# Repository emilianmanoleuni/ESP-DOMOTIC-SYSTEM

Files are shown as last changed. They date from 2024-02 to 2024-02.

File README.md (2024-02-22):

# ESP DOMOTIC SYSTEM
ESP Domotic System is a simple domotic system to control sensors and domotic items of a small house. It is associated to a web app that allows to check real-time graphs of power consumption and sensor readings. The web app also allows to turn on and off domotic items such as lights or fans. This project exploits the concept of embedded systems to simplify control of a small house. It also offers the possibility to give several voice commands through a voice model, for example to turn on or off lights.
### Schematic

 <p>
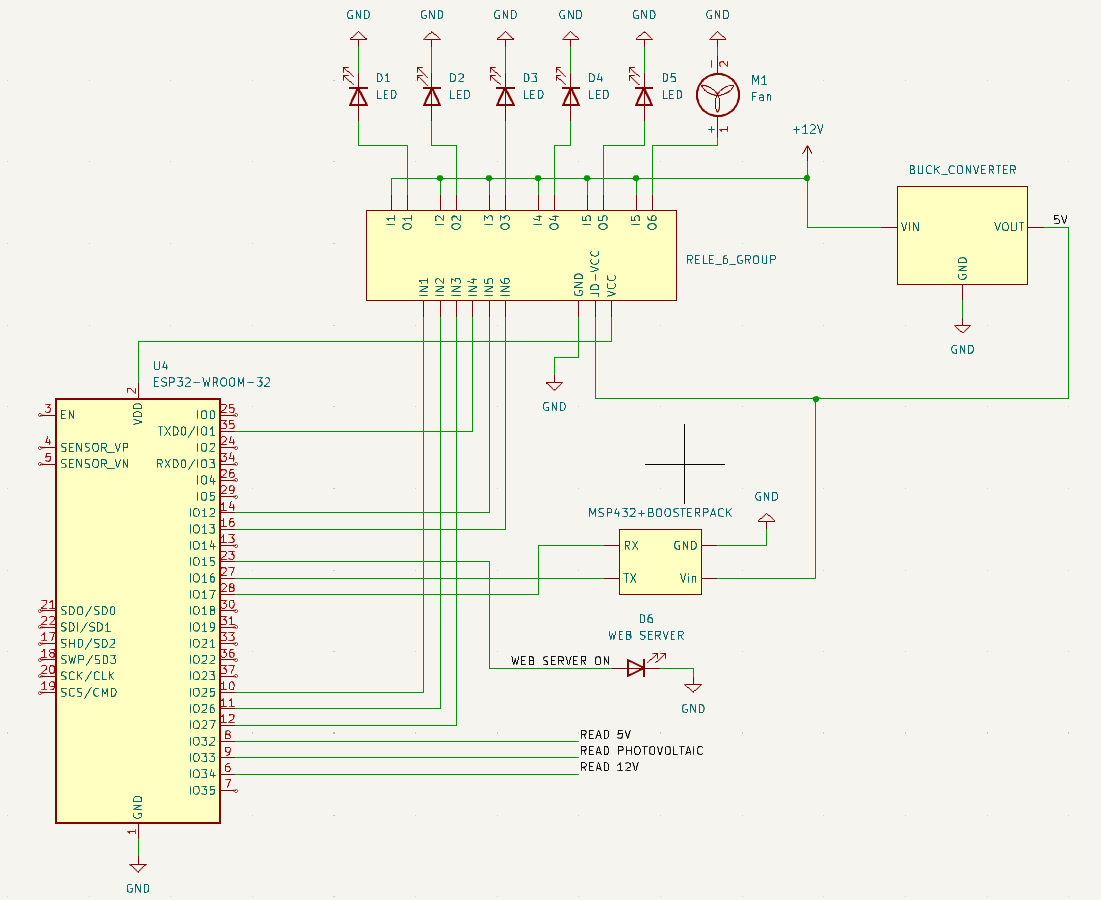
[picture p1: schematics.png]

</p>

 ## Requirements 

 ### Hardware requirements
 ESP Domotyc System requires:
 * Texas Instruments MSP432P401R with BoosterPack
 * 2 x ESP32
 * Relay module
 * Matrix Board
 * Buck converter and resistance
 * INMP441 microphone
 * 5 x LED stripes 12V
 * 12V power supply
 * Solar panel
 * 12V fan

### Software requirements
You will need [Code Composer Studio](https://www.ti.com/tool/CCSTUDIO) installed with [DriverLib](https://www.ti.com/tool/MSPDRIVERLIB) to compile and run the code on the MSP. You will also need [Arduino IDE 1.x](https://www.arduino.cc/en/software) to run the ESPs. 
>Using the 2.x version of the IDE may cause some bugs with the file system

## Project Layout

```

├── esp_main                
│   ├── esp_main_code        # main code to be run on the main esp
│   ├── esp_main_data        # data of the web server held on the esp
├── ESP_SpeechToText         # main code to be run on the voice module esp
├── ServerGoogleAPI          # connection to google server
├── msp432                   # project to be imported in CodeComposerStudio
├── house_model              # 3D model to print house model anb brackets for components
```

## Build and Run the project

After connecting the devices as indicated in the [schematic](#schematic), you have to upload programs on each board.
Starting from the MSP432:
1. Open CodeComposerStudio
2. Go to **File** > **Open Projects from File Systems**
3. In **Import Projects from File Systems** search and select the project.

To add the DriverLib:
1. Go to **Build** > **Arm Linker** > **File Search Path** and add the paths where you installed the library

Once you have done that you can right-click on the main project folder and click on **Build Project**, once ended you can click **Flash** on CCS to upload the code on the MSP432.

For the main ESP: 
1. Open Arduino IDE 1.x
2. Select the board "ESP32 dev module"
3. Go to **File** > **Open** and select the .ino file

For the second ESP: 
1. Open Arduino IDE 1.x
2. Select the board "ESP32 dev module"
3. Go to **File** > **Open** and select the .ino file

> Be sure that the GoogleServerAPI directory is in the same directory as the project and don't rename any file

When you have uploaded and verified both projects, you can upload them on each board by clicking the arrow in Arduino IDE.
To upload the data directory into the memory of the main ESP, you need to use a file system. In this case we use the integrated LittleFS.
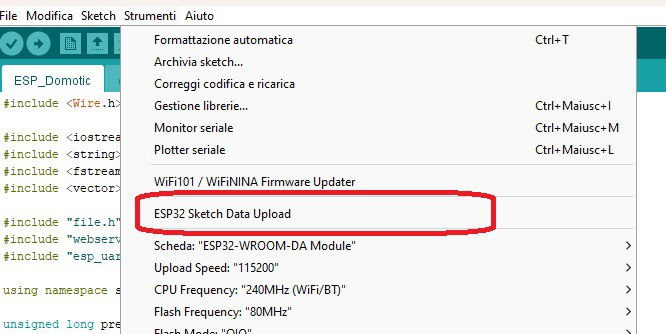
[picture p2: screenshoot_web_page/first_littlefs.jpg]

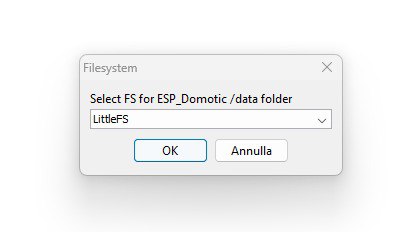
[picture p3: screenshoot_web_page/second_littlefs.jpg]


## User Guide 
 After the connections are ready and the boards are powered, wait that the blue led on the main ESP turn on. This means that the server is ready and you can proceed accessing the web app.
 To do so, open the Arduino console and read the main ESP IP address, copy it into your browser (pay attention to be connected at the same WiFi of the board) and this page will show up:
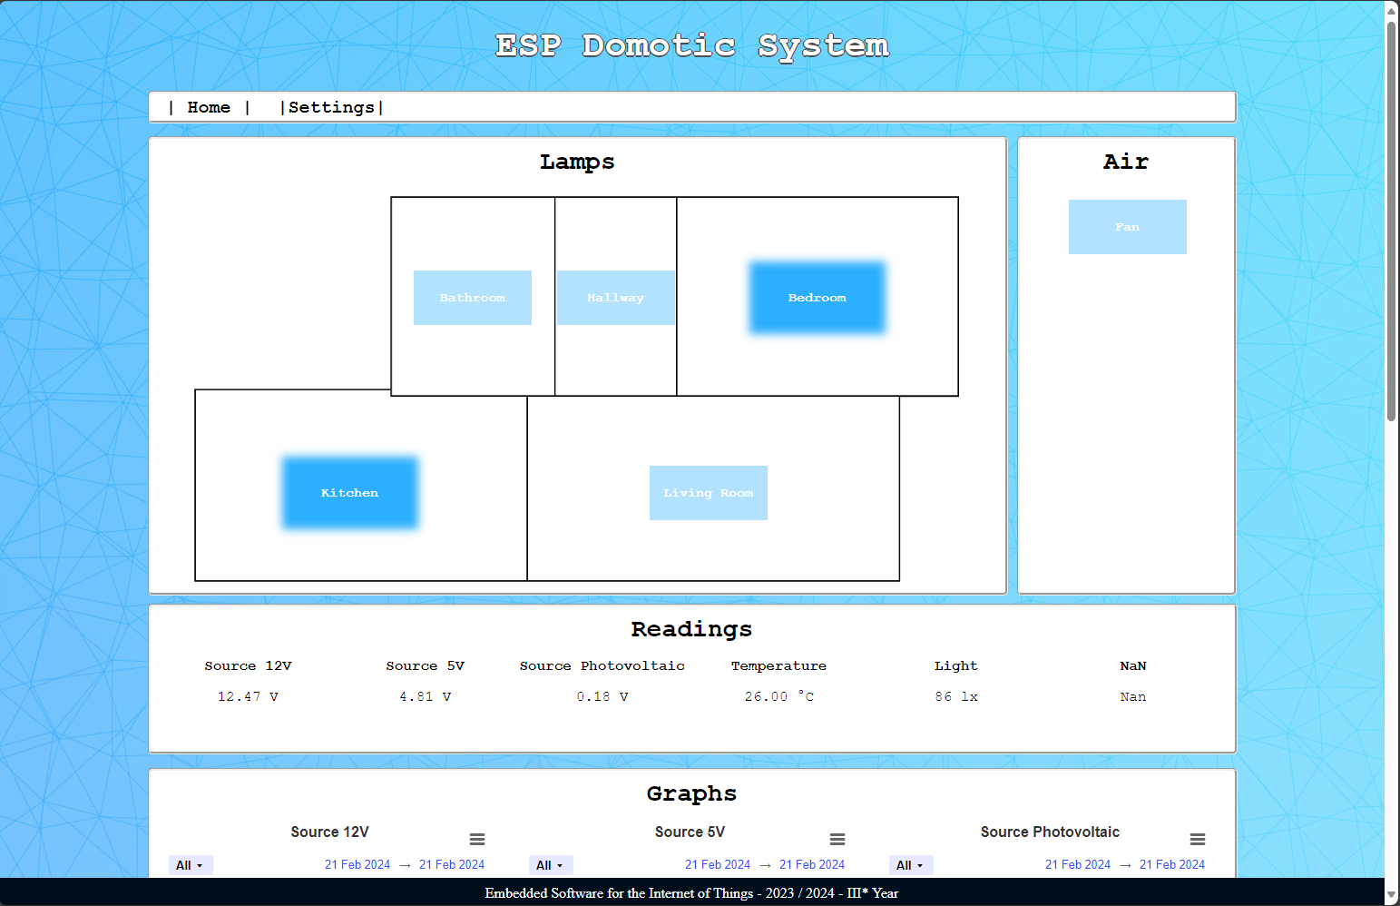
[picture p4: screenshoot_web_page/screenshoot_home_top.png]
 

 >The IP is assigned by the modem after you connect the ESP to it, modifying the ssid and password variables in ESP_Domotic.ino

 You can use those buttons to turn on/off lights and fan. When the blue is bright it means the power is on, otherwise it's off. Scrolling down you will see the graphs, that monitors all the sensors and power supplies of the sistem.

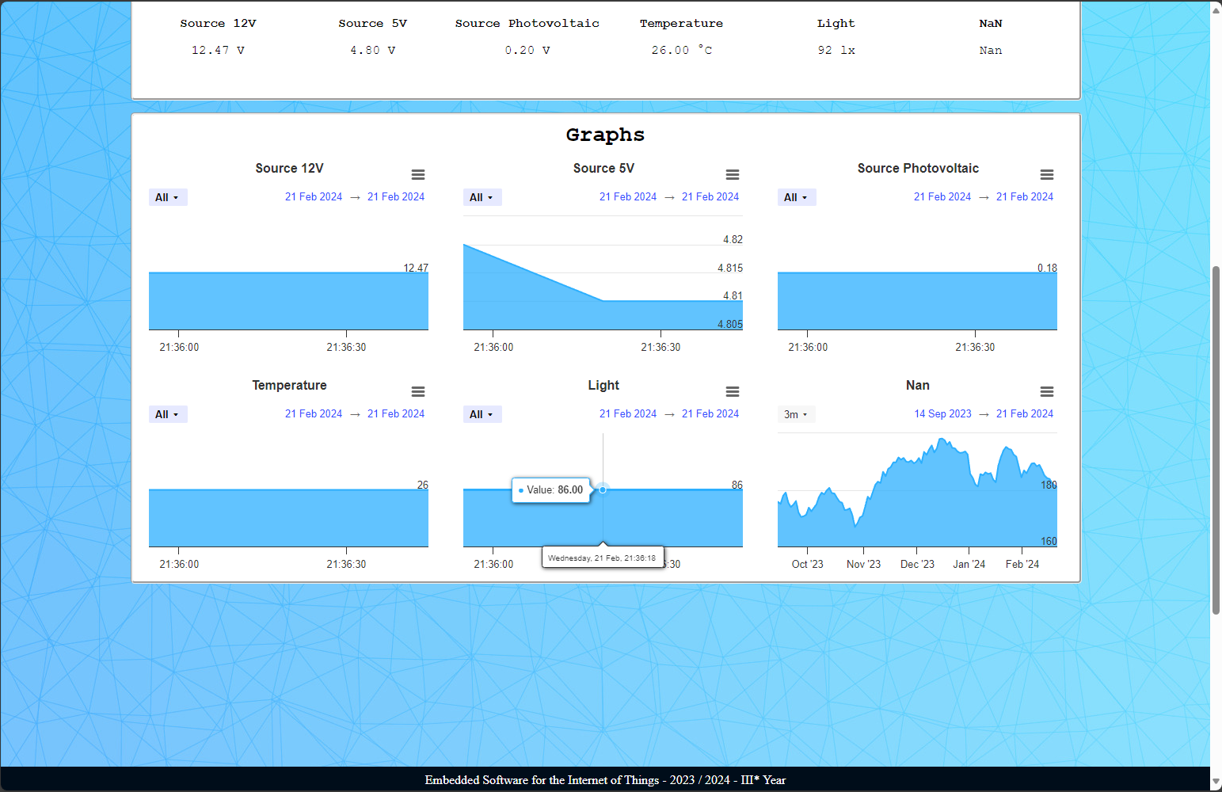
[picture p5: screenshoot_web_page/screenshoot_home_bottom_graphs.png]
 

 You can also use a various set of voice command, composed in this way:
 * If you want to turn or/off lights the command is "_ROOM_ + LIGHTS + ON/OFF"
 * If you want to turn or/off the fan the command is "FAN + ON/OFF"

> Available rooms: LIVING ROOM, KITCHEN, BATHROOM, BEDROOM, HALLWAY.

Just click the button and say the desired command. The command will execute in few seconds.

## Contributors

<table>
    <tr>
        <td>House model and cabling</td>
        <td>Emilian Manole</td>
    </tr>
    <tr>
        <td>Web app and Async server</td>
        <td>Emilian Manole</td>
    </tr>
    <tr>
        <td>MSP432</td>
        <td>Leonardo Rigotti</td>
    </tr>
    <tr>
        <td>UART communication</td>
        <td>Leonardo Rigotti</td>
    </tr>
    <tr>
        <td>First ESP</td>
        <td>Emilian Manole, Leonardo Rigotti</td>
    </tr>
    <tr>
        <td>Second ESP</td>
        <td>Elia Avanzolini, Riccardo Randon</td>
    </tr>
    <tr>
        <td>Voice Module</td>
        <td>Elia Avanzolini, Riccardo Randon</td>
    </tr>
</table>

[Video](https://youtu.be/A26lvR3nOL4) [Presentation](presentation/ESP_DomoticHouse_presentation.pdf)

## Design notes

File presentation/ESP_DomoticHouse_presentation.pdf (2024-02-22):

# DOMOTIC

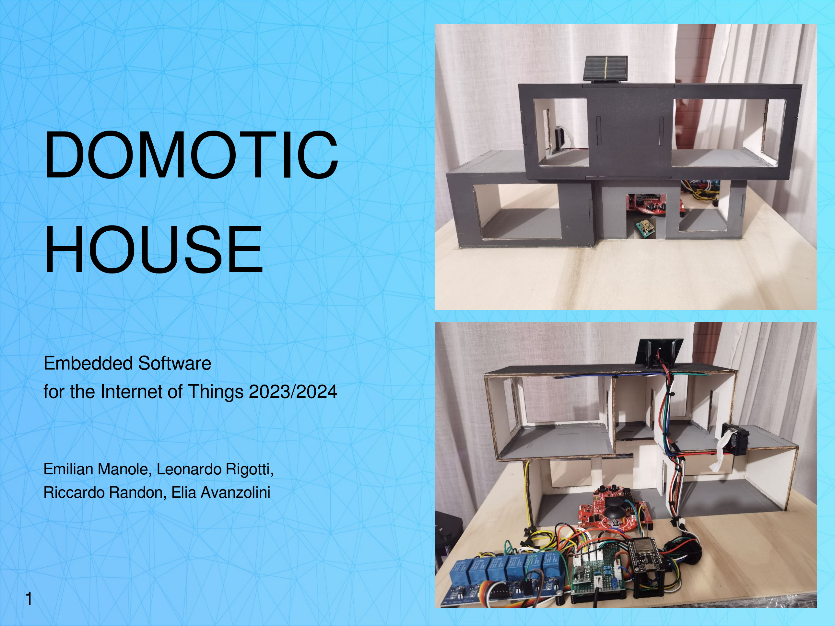
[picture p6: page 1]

# HOUSE

Embedded Software

for the Internet of Things 2023/2024

Emilian Manole, Leonardo Rigotti, Riccardo Randon, Elia Avanzolini

# BASIC MODUS OPERANDI

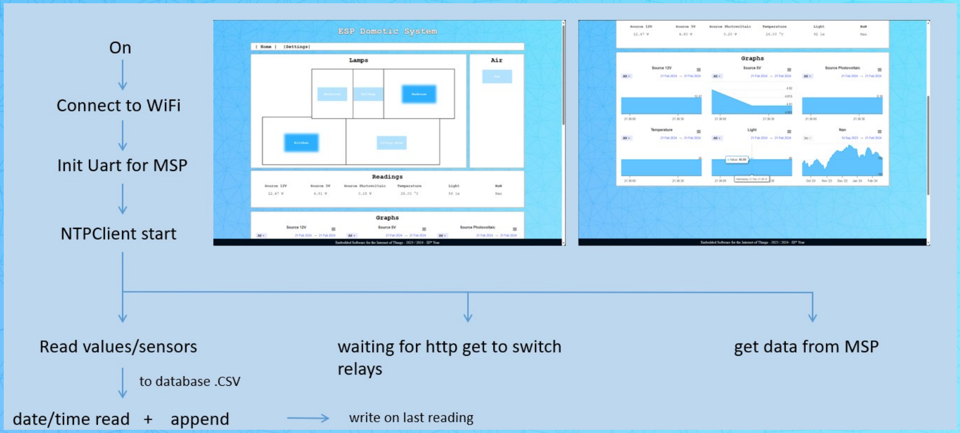
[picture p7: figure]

# MSP432 timer and interrupts

- Continous mode timer
- ACLK at 32kHz, divided by 14 so ~2.2kHz
- Overflows when hits 0xFFFF, around every 28s and sends an interrupt

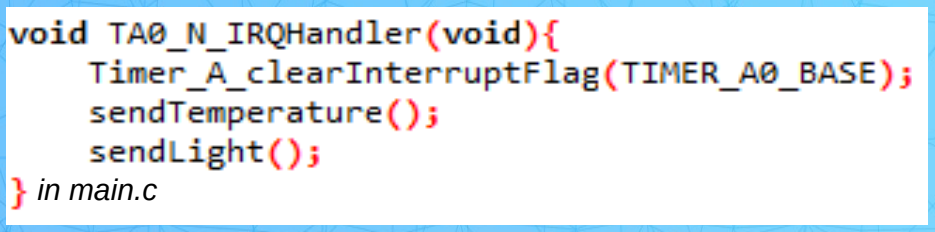
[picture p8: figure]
in main.c

- MCU is in LPM0 (ACLK and SMCLK active)
- ISR sends data via UART to other device
- return to LPM0:
- Interrupt_enableSleepOnIsrExit();
- interrupt on EUSCIA2 (pin 3.2, 3.3)
- executes when something is received via the UART receiver
- stores the data in a global variable and clear flags

# MSP432-ESP32 UART communication

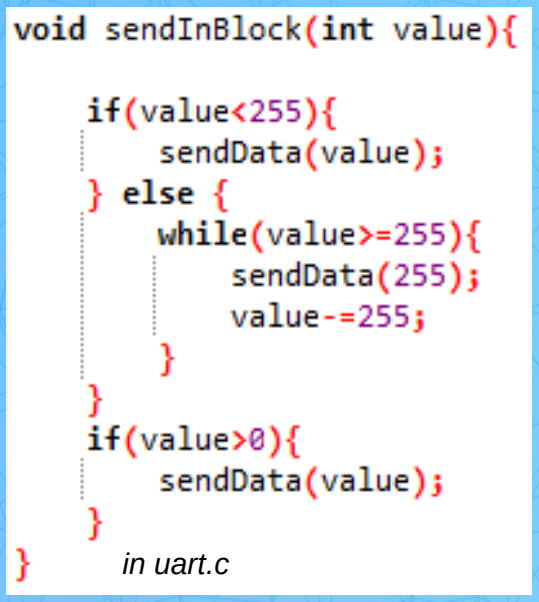
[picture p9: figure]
in uart.c

PROBLEM: only 1 byte via UART SOLUTION: send data that is >=

255 (max value with a byte)
in smaller blocks ...

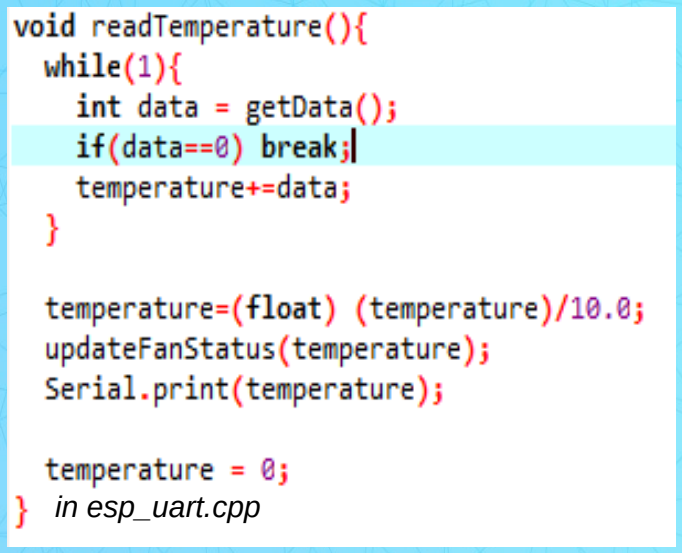
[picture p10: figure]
in esp_uart.cpp

… that get sum up on the ESP side

- EUSCI UART configuration
- 24MHz (SMCLK source), 115200 baudrate, no parity bit, one stop bit, 8 bit long message
- Using eUSCI 2, i.e. pin 3.2 and 3.3

# Voice Command

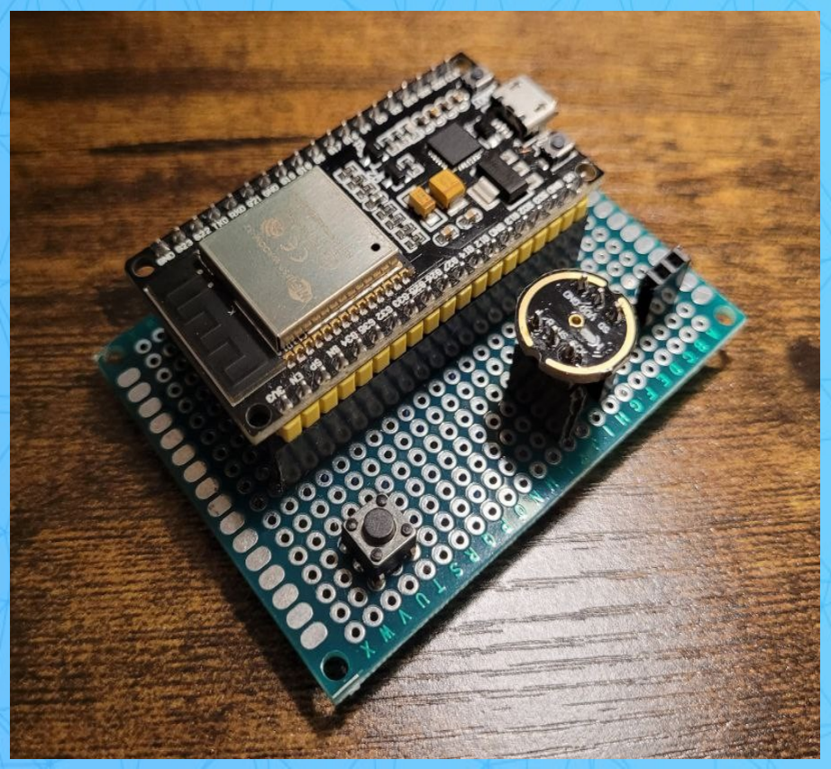
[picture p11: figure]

We utilized an ESP32 board to capture audio signals

from an INMP441 microphone using the I2S protocol.

Due to the high data rate, we employ DMA to store the incoming data in memory.

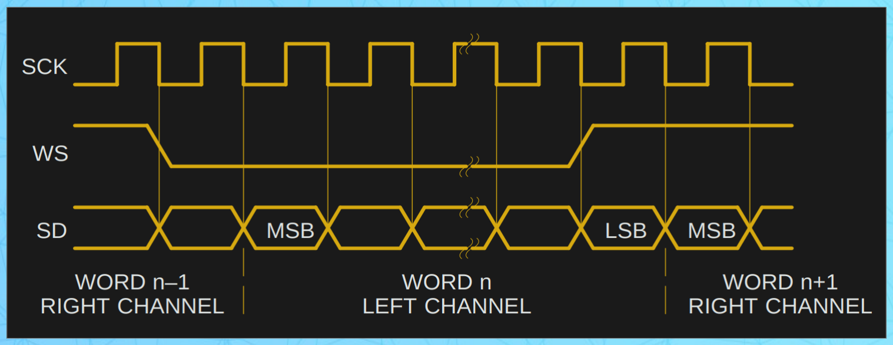
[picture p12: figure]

Afterwards, we utilize flash memory to store the file and produce the necessary WAV audio file format as per Google APIs.

# Speech to Text API

Once we obtain the WAV file, ESP32 sends it to the PC's Python server.
Here, with the assistance of the library provided by Google, we send a request to the Speech-to-Text APIs.

The response comes as a JSON file, which we extract the needed information from,

then send an integer containing home automation configurations back to ESP32.

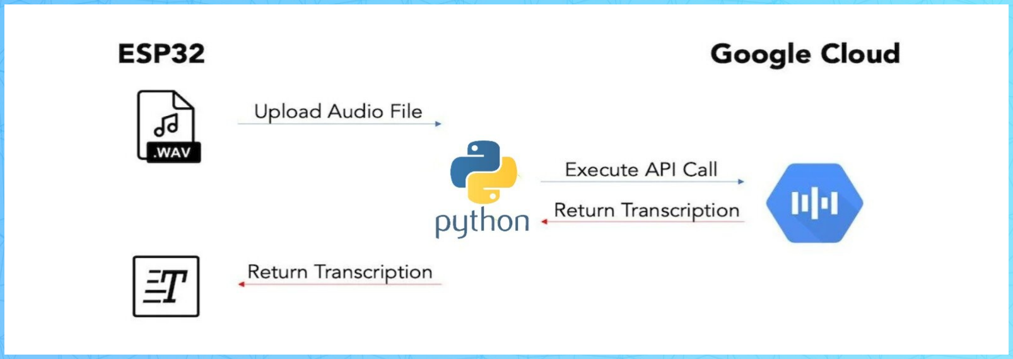
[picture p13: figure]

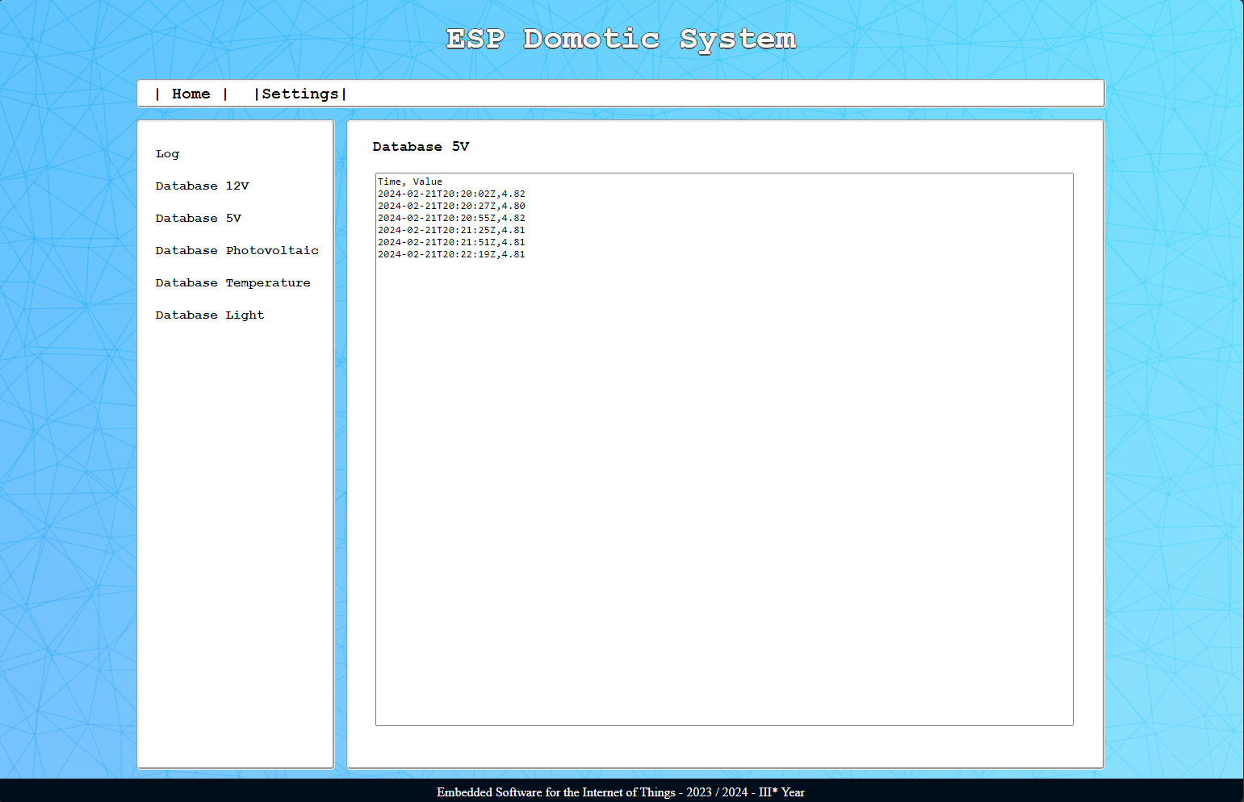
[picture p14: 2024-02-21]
screenshoot_web_page/screenshoot_5v.png

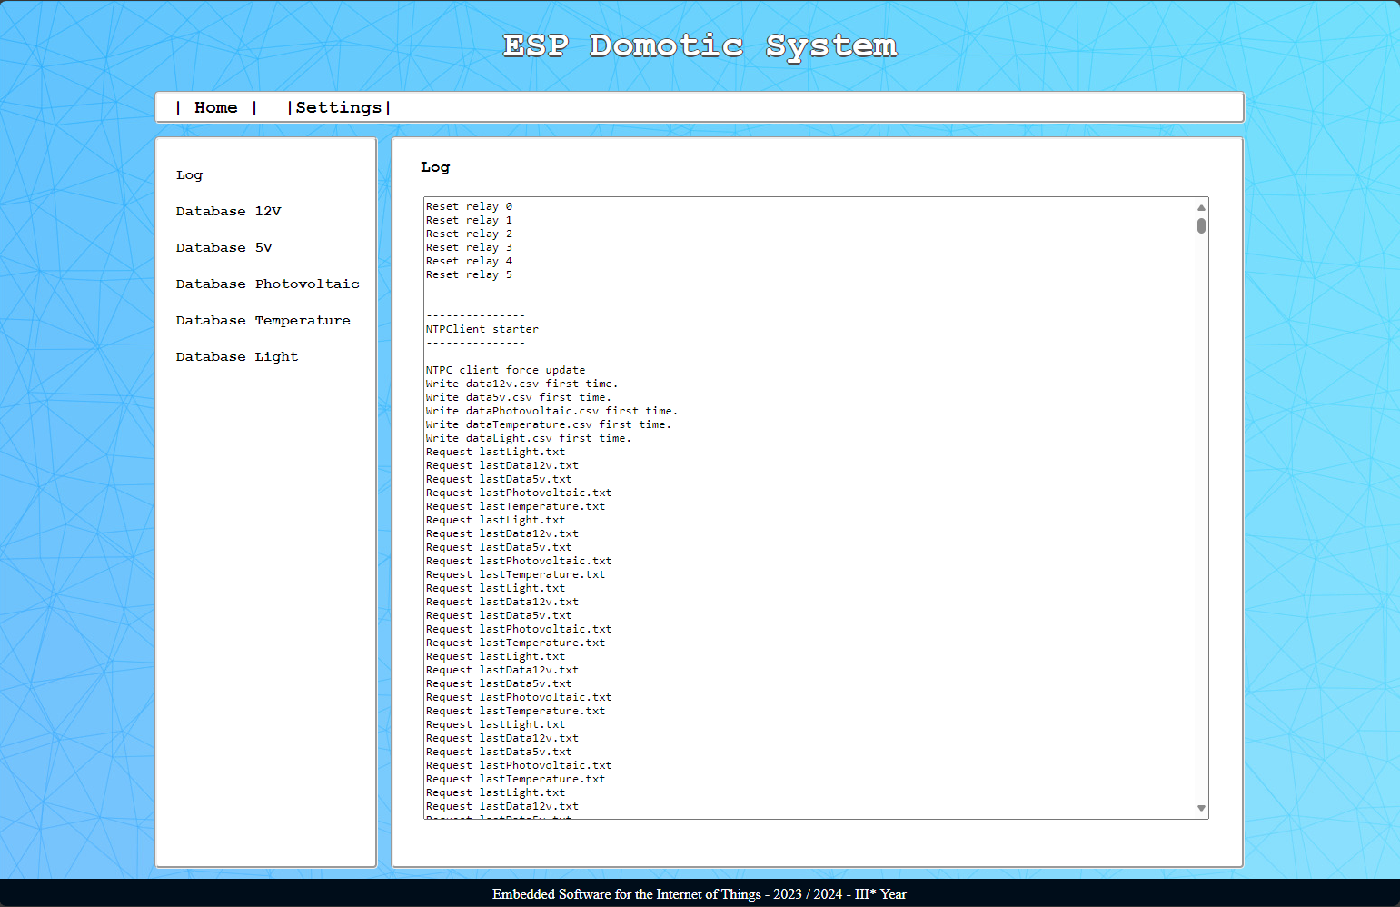
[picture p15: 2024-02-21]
screenshoot_web_page/screenshoot_log.png

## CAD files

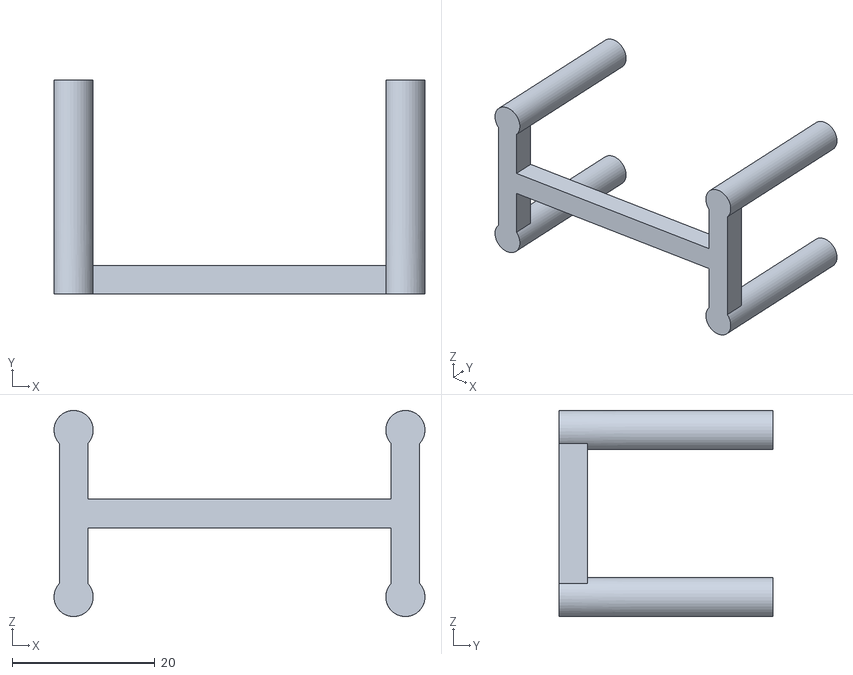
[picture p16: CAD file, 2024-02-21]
house_model/brackets_3D_print/bracketEspHouse.stl
52.0 x 30.0 x 28.9

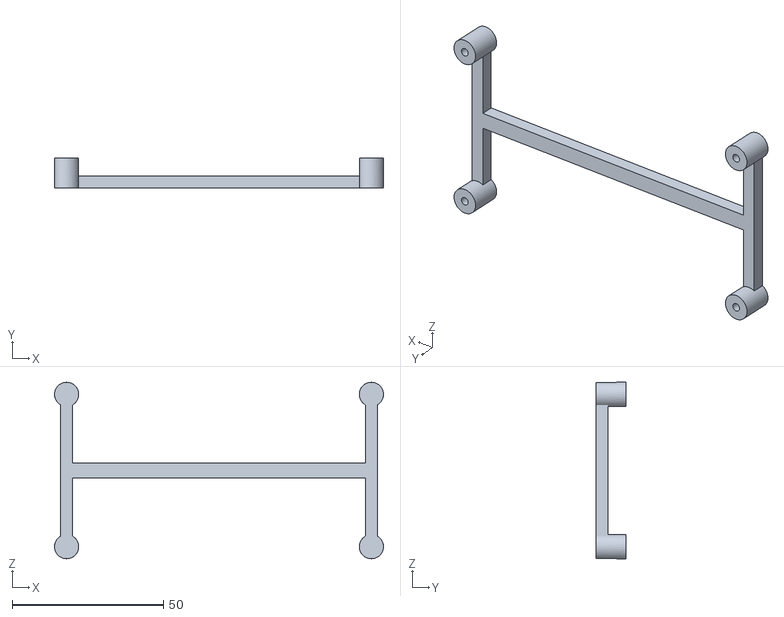
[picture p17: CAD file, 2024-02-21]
house_model/brackets_3D_print/bracketReleGroupHouse.stl
108.7 x 10.0 x 58.3

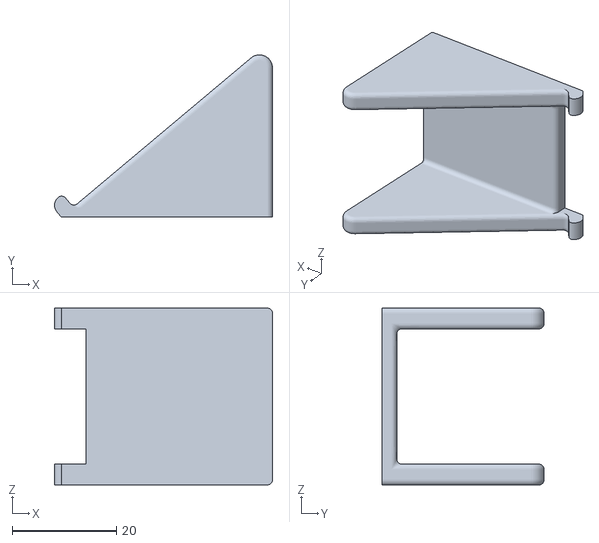
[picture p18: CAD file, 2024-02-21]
house_model/brackets_3D_print/bracketPhotovoltaic.stl
41.9 x 31.2 x 34.0

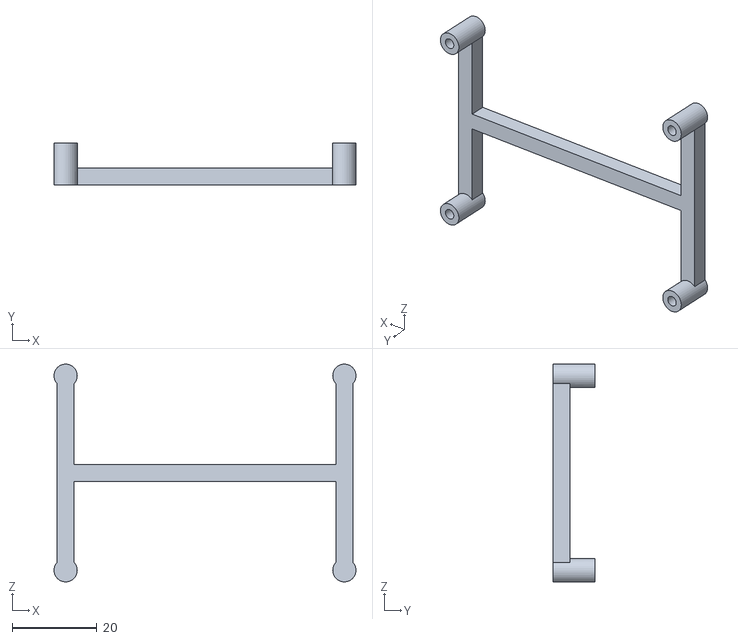
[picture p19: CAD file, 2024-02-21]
house_model/brackets_3D_print/bracketCustomPCB.stl
71.4 x 10.0 x 51.5

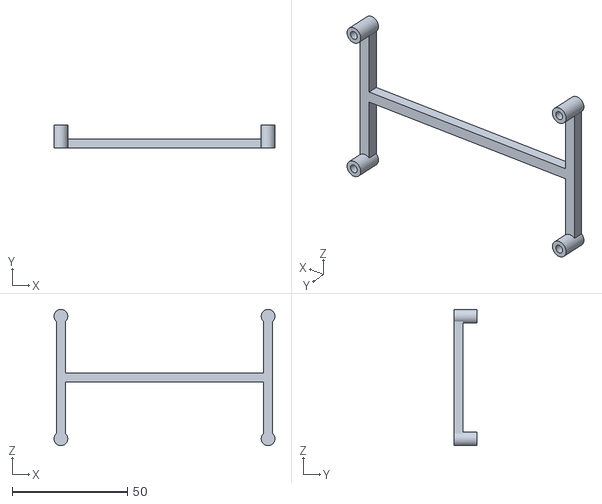
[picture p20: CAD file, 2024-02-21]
house_model/brackets_3D_print/bracketMSP.stl
96.0 x 10.0 x 59.2

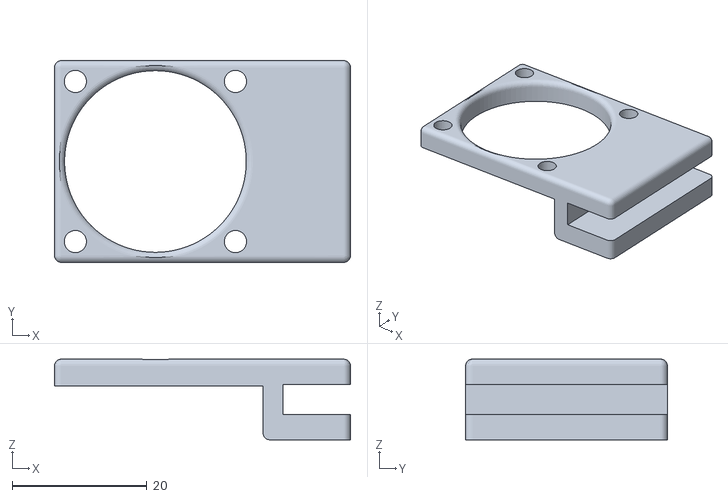
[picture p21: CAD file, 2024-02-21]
house_model/brackets_3D_print/bracketAirFan.stl
44.0 x 30.0 x 12.0

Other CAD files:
house_model/brackets_3D_print/bracketAirFan.f3d
house_model/brackets_3D_print/bracketCustomPcb.f3d
house_model/brackets_3D_print/bracketEspHouse.f3d
house_model/brackets_3D_print/bracketMSP.f3d
house_model/brackets_3D_print/bracketPhotovoltaic.f3d
house_model/brackets_3D_print/bracketReleGroupHouse.f3d

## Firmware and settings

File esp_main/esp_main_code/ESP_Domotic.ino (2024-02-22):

#include <Wire.h>

#include <iostream>
#include <string>
#include <fstream>
#include <vector>

#include "file.h"
#include "webserver.h"
#include "esp_uart.h"

using namespace std;

unsigned long previousMillis = 0;
const long interval = 5000; 

// Pin Rele
int Relay[] = { 33, 26, 27, 14, 12, 13};

//Pin Voltages DON'T use ADC2 with wifi
int PIN_12V = 34;
int PIN_5V = 32;
int PIN_PHOTOVOLTAIC = 33;

// Replace with your network credentials
const char* ssid = "";
const char* password = "";


// Create AsyncWebServer object on port 80
AsyncWebServer server(80);


// Define NTP Client to get time
WiFiUDP ntpUDP;
NTPClient timeClient(ntpUDP);

// Variables to save date and time
String formattedDate;

// Variables to save readings
float readed12V;
float readed5V;
float readedPhotovoltaic;
float temperature  = 0.0;
int light  = 0;

float read12V(){
  return analogRead(PIN_12V) * (12.47/4095.0);
}

float read5V(){
  return analogRead(PIN_5V) * (6.6/4095.0);
}

float readPhotovoltaic(){
  return analogRead(PIN_PHOTOVOLTAIC) * (3.6/4095.0);
}

void setup(){
  //Start log.txt file
  writeFile(LittleFS, "/log.txt", "LOG.TXT FILE ESP DOMOTIC SYSTEM\n--------------------------\n\n");

  //START UART con. with MSP
  UARTinit();                                                                   
  
  Serial.begin(115200);

  // Pin Rele
  for(int i=0; i<sizeof(Relay)/sizeof(int); i++){
    pinMode(Relay[i], OUTPUT);  
  }

  //Pin Led Server On
  pinMode(15, OUTPUT);
  
  //Pin Voltages
  pinMode(PIN_12V, INPUT);
  pinMode(PIN_5V, INPUT);
  pinMode(PIN_PHOTOVOLTAIC, INPUT);
  
  bool status; 
  if(!LittleFS.begin()){
    Serial.println("An Error has occurred while mounting LITTLEFS");
    return;
  }

  // Connect to Wi-Fi
  WiFi.begin(ssid, password);
  while (WiFi.status() != WL_CONNECTED) {
    delay(1000);
    Serial.println("Connecting to WiFi..");
  }

  // Print ESP32 Local IP Address
  digitalWrite(15, HIGH);
  Serial.println(WiFi.localIP());

  delay(1000);
  // Reset Rele
  for(int i = 0; i<sizeof(Relay)/sizeof(int); i++){
    Serial.print("Reset relay ");
    appendFile(LittleFS, "/log.txt", "Reset relay ");
    Serial.print(i);
    appendFile(LittleFS, "/log.txt", String((i)).c_str());
    Serial.print("\n");
    appendFile(LittleFS, "/log.txt", "\n");
    digitalWrite(Relay[i], LOW);  
    delay(1000);
  }

  // Initialize a NTPClient to get time
  timeClient.begin();
  // Set offset time in seconds to adjust for your timezone, for example:
  // GMT +1 = 3600
  // GMT +8 = 28800
  // GMT -1 = -3600
  // GMT 0 = 0
  //timeClient.setTimeOffset(3600);

  appendFile(LittleFS, "/log.txt", "\n\n---------------\nNTPClient starter\n---------------\n\n");

  // Route for root / web page
  server.on("/", HTTP_GET, [](AsyncWebServerRequest *request){
    request->send(LittleFS, "/index.html");
    appendFile(LittleFS, "/log.txt", "Request index.html\n");
  });
  //Components
  server.on("/settings.html", HTTP_GET, [](AsyncWebServerRequest *request){
    request->send(LittleFS, "/settings.html");
    appendFile(LittleFS, "/log.txt", "Request settings.html\n");
  });
  server.on("/style.css", HTTP_GET, [](AsyncWebServerRequest * request){
    request->send(LittleFS, "/style.css", "text/css");
    appendFile(LittleFS, "/log.txt", "Request style.cssl\n");
  });
  server.on("/casa_grafica.png", HTTP_GET, [](AsyncWebServerRequest * request){
    request->send(LittleFS, "/casa_grafica.png", "image/png");
    appendFile(LittleFS, "/log.txt", "Request casa_grafica.png\n");
  });
  server.on("/background.jpg", HTTP_GET, [](AsyncWebServerRequest * request){
    request->send(LittleFS, "/background.jpg", "image/jpg");
    appendFile(LittleFS, "/log.txt", "Request background.jpg\n");
  });
  
  //Readings and Databases
  //Database
  server.on("/log.txt", HTTP_GET, [](AsyncWebServerRequest * request){
    request->send(LittleFS, "/log.txt", "text/txt");
    appendFile(LittleFS, "/log.txt", "Request log.txt\n");
  });
  server.on("/data12v.csv", HTTP_GET, [](AsyncWebServerRequest * request){
    request->send(LittleFS, "/data12v.csv", "text/csv");
    appendFile(LittleFS, "/log.txt", "Request data12v.csv\n");
  });
  server.on("/data5v.csv", HTTP_GET, [](AsyncWebServerRequest * request){
    request->send(LittleFS, "/data5v.csv", "text/csv");
    appendFile(LittleFS, "/log.txt", "Request data5v.csv\n");
  });
  server.on("/dataPhotovoltaic.csv", HTTP_GET, [](AsyncWebServerRequest * request){
    request->send(LittleFS, "/dataPhotovoltaic.csv", "text/csv");
    appendFile(LittleFS, "/log.txt", "Request dataPhotovoltaic.csv\n");
  });
  server.on("/dataTemperature.csv", HTTP_GET, [](AsyncWebServerRequest *request){
    request->send(LittleFS, "/dataTemperature.csv", "text/csv");
    appendFile(LittleFS, "/log.txt", "Request dataTemperature\n");
  });
  server.on("/dataLight.csv", HTTP_GET, [](AsyncWebServerRequest *request){
    request->send(LittleFS, "/dataLight.csv", "text/csv");
    appendFile(LittleFS, "/log.txt", "Request dataLight\n");
  });
  
  //Last single reading
  server.on("/lastData12v.txt", HTTP_GET, [](AsyncWebServerRequest * request){
    request->send(LittleFS, "/lastData12v.txt", "text/txt");
    appendFile(LittleFS, "/log.txt", "Request lastData12v.txt\n");
  });
  server.on("/lastData5v.txt", HTTP_GET, [](AsyncWebServerRequest * request){
    request->send(LittleFS, "/lastData5v.txt", "text/txt");
    appendFile(LittleFS, "/log.txt", "Request lastData5v.txt\n");
  });
  server.on("/lastPhotovoltaic.txt", HTTP_GET, [](AsyncWebServerRequest * request){
    request->send(LittleFS, "/lastPhotovoltaic.txt", "text/txt");
    appendFile(LittleFS, "/log.txt", "Request lastPhotovoltaic.txt\n");
  });
  server.on("/lastTemperature.txt", HTTP_GET, [](AsyncWebServerRequest * request){
    request->send(LittleFS, "/lastTemperature.txt", "text/txt");
    appendFile(LittleFS, "/log.txt", "Request lastTemperature.txt\n");
  });
  server.on("/lastLight.txt", HTTP_GET, [](AsyncWebServerRequest * request){
    request->send(LittleFS, "/lastLight.txt", "text/txt");
    appendFile(LittleFS, "/log.txt", "Request lastLight.txt\n");
  });

  

  //First write on LOG
  timeClient.forceUpdate();
  formattedDate = timeClient.getFormattedDate();
  appendFile(LittleFS, "/log.txt", "NTPC client force update\n");


  //Reset and write on Database
  readed12V = read12V();
  writeFile(LittleFS, "/data12v.csv", ("Time, Value\n"+formattedDate+",").c_str());
  appendFile(LittleFS, "/data12v.csv", (String(readed12V)+"\r").c_str());
  appendFile(LittleFS, "/log.txt", "Write data12v.csv first time.\n");

  readed5V = read5V();
  writeFile(LittleFS, "/data5v.csv", ("Time, Value\n"+formattedDate+",").c_str());
  appendFile(LittleFS, "/data5v.csv", (String(readed5V)+"\r").c_str());
  appendFile(LittleFS, "/log.txt", "Write data5v.csv first time.\n");

  readedPhotovoltaic = readPhotovoltaic();
  writeFile(LittleFS, "/dataPhotovoltaic.csv", ("Time, Value\n"+formattedDate+",").c_str());
  appendFile(LittleFS, "/dataPhotovoltaic.csv", (String(readedPhotovoltaic)+"\r").c_str());
  appendFile(LittleFS, "/log.txt", "Write dataPhotovoltaic.csv first time.\n");

  temperature = readTemperature();
  writeFile(LittleFS, "/dataTemperature.csv", ("Time, Value\n"+formattedDate+",").c_str());
  appendFile(LittleFS, "/dataTemperature.csv", (String(temperature)+"\r").c_str());
  appendFile(LittleFS, "/log.txt", "Write dataTemperature.csv first time.\n");
  
  light = readLight();
  writeFile(LittleFS, "/dataLight.csv", ("Time, Value\n"+formattedDate+",").c_str());
  appendFile(LittleFS, "/dataLight.csv", (String(light)+"\r").c_str());
  appendFile(LittleFS, "/log.txt", "Write dataLight.csv first time.\n");



  //Voltages //DEPRECATED no more client request
  /*
  server.on("/read12V", HTTP_GET, [](AsyncWebServerRequest *request){
    float readed12V = read12V();
    request->send(200, "text/plain", String(readed12V));
    Serial.print("Read 12v:");
    Serial.print(readed12V);
    Serial.print("\n");

    timeClient.forceUpdate();
    formattedDate = timeClient.getFormattedDate();

    //Database
    appendFile(LittleFS, "/data12v.csv", (formattedDate+",").c_str());
    appendFile(LittleFS, "/data12v.csv", (String(readed12V)+"\r").c_str());
    //LastRead
    writeFile(LittleFS, "/lastData12v.txt", (String(readed12V)).c_str());
  });
  
  //DEPRECATED no more client request
  server.on("/read5V", HTTP_GET, [](AsyncWebServerRequest *request){
    float readed5V = read5V();
    request->send(200, "text/plain", String(readed5V));
    Serial.print("Read 5v:");
    Serial.print(readed5V);
    Serial.print("\n");

    timeClient.forceUpdate();
    formattedDate = timeClient.getFormattedDate();

    //Database
    appendFile(LittleFS, "/data5v.csv", (formattedDate+",").c_str());
    appendFile(LittleFS, "/data5v.csv", (String(readed5V)+"\r").c_str());
    //LastRead
    writeFile(LittleFS, "/lastData5v.txt", (String(readed5V)).c_str());
  });
  */



  //Rele 
  server.on("/relay1/on", HTTP_GET, [](AsyncWebServerRequest *request){
    request->send(LittleFS,"/index.html");
    digitalWrite(Relay[0], HIGH);
    Serial.println("Relay 1 ON");
  });
  server.on("/relay1/off", HTTP_GET, [](AsyncWebServerRequest *request){
    request->send(LittleFS,"/index.html");
    digitalWrite(Relay[0], LOW);
    Serial.println("Relay 1 OFF");
  }); 

  server.on("/relay2/on", HTTP_GET, [](AsyncWebServerRequest *request){
    request->send(LittleFS,"/index.html");
    digitalWrite(Relay[1], HIGH);
    Serial.println("Relay 2 ON");
  });
  server.on("/relay2/off", HTTP_GET, [](AsyncWebServerRequest *request){
    request->send(LittleFS,"/index.html");
    digitalWrite(Relay[1], LOW);
    Serial.println("Relay 2 OFF");
  }); 

  server.on("/relay3/on", HTTP_GET, [](AsyncWebServerRequest *request){
    request->send(LittleFS,"/index.html");
    digitalWrite(Relay[2], HIGH);
    Serial.println("Relay 3 ON");
  });
  server.on("/relay3/off", HTTP_GET, [](AsyncWebServerRequest *request){
    request->send(LittleFS,"/index.html");
    digitalWrite(Relay[2], LOW);
    Serial.println("Relay 3 OFF");
  }); 

  server.on("/relay4/on", HTTP_GET, [](AsyncWebServerRequest *request){
    request->send(LittleFS,"/index.html");
    digitalWrite(Relay[3], HIGH);
    Serial.println("Relay 4 ON");
  });
  server.on("/relay4/off", HTTP_GET, [](AsyncWebServerRequest *request){
    request->send(LittleFS,"/index.html");
    digitalWrite(Relay[3], LOW);
    Serial.println("Relay 4 OFF");
  }); 

  server.on("/relay5/on", HTTP_GET, [](AsyncWebServerRequest *request){
    request->send(LittleFS,"/index.html");
    digitalWrite(Relay[4], HIGH);
    Serial.println("Relay 5 ON");
  });
  server.on("/relay5/off", HTTP_GET, [](AsyncWebServerRequest *request){
    request->send(LittleFS,"/index.html");
    digitalWrite(Relay[4], LOW);
    Serial.println("Relay 5 OFF");
  }); 
  
  server.on("/relay6/on", HTTP_GET, [](AsyncWebServerRequest *request){
    request->send(LittleFS,"/index.html");
    digitalWrite(Relay[5], HIGH);
    Serial.println("Relay 6 ON");
  });
  server.on("/relay6/off", HTTP_GET, [](AsyncWebServerRequest *request){
    request->send(LittleFS,"/index.html");
    digitalWrite(Relay[5], LOW);
    Serial.println("Relay 6 OFF");
  });



    
  // Start server
  server.begin();
  
}
 
void loop(){
  unsigned long currentMillis = millis();
  if (currentMillis - previousMillis >= interval) {
    previousMillis = currentMillis;

    readed12V = read12V();
    readed5V = read5V();
    readedPhotovoltaic = readPhotovoltaic();
    temperature = readTemperature();
    light = readLight();
    
    timeClient.forceUpdate();
    formattedDate = timeClient.getFormattedDate();

    //Database 12V
    appendFile(LittleFS, "/data12v.csv", (formattedDate+",").c_str());
    appendFile(LittleFS, "/data12v.csv", (String(readed12V)+"\r").c_str());
    //LastRead
    writeFile(LittleFS, "/lastData12v.txt", (String(readed12V)).c_str());

    //Database 5V
    appendFile(LittleFS, "/data5v.csv", (formattedDate+",").c_str());
    appendFile(LittleFS, "/data5v.csv", (String(readed5V)+"\r").c_str());
    //LastRead
    writeFile(LittleFS, "/lastData5v.txt", (String(readed5V)).c_str());

    //Database Photovoltaic
    
    appendFile(LittleFS, "/dataPhotovoltaic.csv", (formattedDate+",").c_str());
    appendFile(LittleFS, "/dataPhotovoltaic.csv", (String(readedPhotovoltaic)+"\r").c_str());
    appendFile(LittleFS, "/log.txt", "Write dataPhotovoltaic.csv first time.\n");
    //LastRead
    writeFile(LittleFS, "/lastPhotovoltaic.txt", (String(readedPhotovoltaic)).c_str());

    //Database Temperature
    appendFile(LittleFS, "/dataTemperature.csv", (formattedDate+",").c_str());
    appendFile(LittleFS, "/dataTemperature.csv", (String(temperature)+"\r").c_str());
    //LastRead
    writeFile(LittleFS, "/lastTemperature.txt", (String(temperature)).c_str());

    //Database Light
    appendFile(LittleFS, "/dataLight.csv", (formattedDate+",").c_str());
    appendFile(LittleFS, "/dataLight.csv", (String(light)+"\r").c_str());
    //LastRead
    writeFile(LittleFS, "/lastLight.txt", (String(light)).c_str());
    
  }
}

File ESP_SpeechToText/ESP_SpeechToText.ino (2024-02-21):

#include <Arduino.h>
#include <HardwareSerial.h>
#include "ClientSpeechText.h"
#include "INMP441.h"
#include "wav.h"


#define BUTTON_PIN 18       // button pin, pull-up
#define DEBOUNCE_DELAY 50   // delay for anti debouncing precedure
#define BUFFER_LEN  1024*2  // lenght of buffers, dma ecc.
#define RX_PIN 16           // serial pins
#define TX_PIN 17

// microphone variables
byte samplesBuff[BUFFER_LEN];
int32_t flash_wr_size;
size_t bytes_read;  

// button variables
int lastButtonState = HIGH;  
unsigned long lastDebounceTime = 0;  

// declaration microphone object
INMP441 mic;




void setup() {
  Serial.begin(115200);
  // input button internal pull-up
  Serial2.begin(115200, SERIAL_8N1, RX_PIN, TX_PIN);
  pinMode(BUTTON_PIN, INPUT_PULLUP);
  // microphone init
  mic.init();
  
}

void loop() {
  
  while(bool buttonState = debounceButton());
  Serial.println("Button pressed");

  // start recording and save file
  Serial.println("\n new record");
  delay(500);
  Wav* wav = new Wav();
  flash_wr_size = 0;
  Serial.print("arrivo");
  
  mic.reset();

  Serial.println(" *** Recording Start *** ");
  wav->bodyOpen("w");
  while (flash_wr_size < FLASH_RECORD_SIZE) {
    i2s_read(I2S_PORT, &samplesBuff, BUFFER_LEN, &bytes_read, portMAX_DELAY);
    wav->writeBody(samplesBuff, bytes_read);
    flash_wr_size += bytes_read;  
    ets_printf("Sound recording %u%%\n", flash_wr_size * 100 / FLASH_RECORD_SIZE);
  }
  wav->bodyClose();
  wav->writeFile();
  delay(1000);
  wav->listLittleFS();

  //wav.encodeFile();
  //wav.listLittleFS();

  // send file to server
  CloudSpeechClient* cloudspeechclient = new CloudSpeechClient();
  int message = cloudspeechclient->sendFile(FILENAME);

  Serial2.println(message);
  
  delete cloudspeechclient;
  delete wav;

  
  delay(5000);
}



bool debounceButton() {
 
  int buttonState = digitalRead(BUTTON_PIN);
  
  if (buttonState != lastButtonState) lastDebounceTime = millis();
  

  if ((millis() - lastDebounceTime) > DEBOUNCE_DELAY) buttonState = lastButtonState;

  lastButtonState = buttonState;
  return buttonState;
}
